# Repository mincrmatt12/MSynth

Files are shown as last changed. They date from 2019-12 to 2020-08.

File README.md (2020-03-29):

# MSynth

A simple-ish digital desktop synthesizer unit, on woefully underpowered hardware.

(well it's an STM32F429, it's really just RAM-limited, but hey it only costs ~57 cad for parts + pcbs + assembly)

## Architecture

The project is split up into multiple subprojects, each contained in a folder. They all have READMEs related to their internal structure.
User-facing documentation (i.e. a guide) is stored in the `docs/` folder.

The various subprojects are:

- `bmap`: various resource generation tools
- `board`: PCB CAD files + schematic 
- `bootloader`: The MSynth Bootloader, responsible for installation/updating/management/booting of applications and filesystem management/cleanup.
- `factory`: Test application for verifying board accuracy, component quality and basic unit tests.
- `framework`: Common code and build setup for all applications (clock setup, peripheral access code, filesystem code, etc.)
- `fstool`: Tools for generating and interacting with filesystem images
- `app`: Various primary apps are placed here. The most important one is `main_app`, which is the actual synthesizer core.

## Licensing

The MSynth project _source code_ is licensed under the ISC license (see LICENSE.txt). 
Note that any output of MSynth units is _NOT_ covered by this license; you are free to do literally anything with the audio that comes out of this project, and no warranty is provided
for these outputs (again, see LICENSE.txt).

Various font resources used (Lato and DejaVu Sans) are optionally used during the compilation process, but not included here; if you wish to avoid licensing restrictions
you may substitute other or custom fonts with more favorable licensing. 

Any graphical resources (_only in their source form in this repository_), including logos are licensed under the CC-BY-SA-4.0 license. (see LICENSE-graphics.txt)

Copyright (c) 2020, Matthew Mirvish

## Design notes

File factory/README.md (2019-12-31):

# factory

This is the "factory" testing / calibration application, which is normally installed in the TEST slot.

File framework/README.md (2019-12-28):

# MSynth App Framework

This is our replacement for platformio, since it wasn't up to this particular task.

## Create new bucket

(internal name for a set of apps)

- Copy the template cmakelists to a new folder.
- Customize it.
- Run cmake, passing `-DCMAKE_TOOLCHAIN_FILE=<path to toolchain.cmake>`
- Run cmake again, not passing the toolchain (it doesn't work the first time for whatever reason)

## Structure

```
|
-- ld: link script
-- startup: startup (+ header generation) asm
-- lib: common library for msynth
```

## App structure

Currently just contains a `src` folder per app, with all the sources.
Eventually, this will contain places to put filesystem resources/etc.

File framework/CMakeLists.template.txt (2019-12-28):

cmake_minimum_required(VERSION 3.3)
project(bucket_name_here C CXX ASM)

include(${CMAKE_CURRENT_LIST_DIR}/../framework/build.cmake)  # point at the right dir

# setup an APP
add_app(
	# folder /target name
	factory_app
	# name
	"FactoryTest"
	# appID
	"FTsc"
	# appSIZE
	16
	# flags
	TEST
	LOWSCREEN
	FS
	# valid options are: PRIMARY TEST EEPROM FS LOWSCREEN APPCMD
)

# setup an upload target
create_uploader(
	# name of taregt (to use with make)
	upload_factory
	# name of app
	factory_app
	# sector
	1
)

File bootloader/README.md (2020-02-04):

# bootloader

The MSynth bootloader is designed to allow booting of:

- one PRIMARY application (the synthesizer itself)
- one TEST application (the "factory test" )
- any number of SECONDARY applications

These applications are contained in SECTORS, which reside in contiguous flash sectors. Each sector contains a single application. The bootloader enumerates all sectors to find valid
applications.  When booting normally, the first (and only legal) PRIMARY application found is launched. If F1 and F2 are held while booting, the first (and only legal) TEST application is launched. If the
PRIMARY application cannot be found, but the TEST application can be, the TEST application is launched, otherwise the boot-menu appears. If all three mode buttons are held while booting, the boot-menu appears.

## Application Header

Each application has the following header, placed at the sector start:

| Offset | Format | Description |
| ---- | ---| --- |
| 0x00 | `"MAPP"` | 4-byte magic |
| 0x04 | char[32] | Null terminated name |
| 0x24 | u32 | Vector table offset |
| 0x28 | u32 | Entry point |
| 0x2C | char[4] | APPID |
| 0x30 | u16 | Flags |
| 0x34 | u32 | Debug data pointer (0 if not present) |
| 0x38 | u32 | Initial stack pointer |
| 0x3C | u32 | Length of application data |

The flags are:

```
                            LSB
  
X 000 10 1 01100      1 10 10                
| ||| || | |////      | |/ ||
| ||| || | |          | |  |-is PRIMARY
| ||| || | |          | |  --is TEST
| ||| || | -FSuse slot| --EEPROM slot used
| ||| || -uses FS     --uses EEPROM       
| ||| |--uses LOWscreen RAM layout
| ||| --is installed                         
| ||-- supports APPCMDs                     
| |-- uses the SD card
| -- uses the USB port
-- unused
```

The slot entries are added by the bootloader if isinstalled is not set, or during installation, if their enable bits are set. If the `LOWscreen` flag is set, the bootloader will assume the screen is setup as a
single-layer 8bpp located at the beginning of SRAM1 and SRAM2. This allows it to write messages over top of the application screen, which is useful in some cases. It assumes color 0 is black and color 1 is white.

## Memory Map

The first sector (and possibly second, depending on bootloader size) is reserved by the bootloader. No headers are present, there is effectively just a small application loaded into flash (i.e. an ISR table at flash
address 0)

The data in SRAM and CCMRAM are undefined, however in general it is split into 3 logical zones:
- SRAM1 & SRAM2 are VRAM (upper 512 bytes unused)
- SRAM3 is RAM
- CCMRAM is CCMRAM

The data in the upper 128 bytes of BKPRAM is the bootloader serialization area. When the bootloader starts, it reads from here and when it ends it writes to here.

The bootloader reserves the first 8 bytes of EEPROM.

## Bootloader Serialization Data

| Offset | Format | Description |
| --- | --- | --- |
| 0x00 | `"MBLD"` | 4-byte magic |
| 0x04 | u8 | Init flags |
| 0x05 | u8 | Boot command |
| 0x08 | u32[8] | Boot command parameters |
| 0x28 | u8 | Boot mode |
| 0x2C | u32 | PTR to APPINFO |
| 0x30 | u8 | App Special Command |
| 0x34 | u32[8] | App command parameters |
| 0x54 | u32 | App command return value |

The init flags are set based on which parts of the data are valid. These flags are:

```
		LSB
XXXX 0000
|/// ||||
|    |||-- Boot command set
|    ||-- Boot mode/APPINFO set
|    |-- App special command set
|    -- App return pointer set
-- unused
```

For example, when an application boots, bit 1 should be set, and if the bootloader is calling a special routine in the ap, bit 2 will also be set.
If an application wants to trigger a command, it should write data to the correct offsets and set bit 0, then reset.

### Boot Mode

The boot mode indicates what events caused the app to start executing, an enumeration of:

| Value | Name |
| ----- | ---- |
| 0x00  | UNKNOWN_BOOT |
| 0x10  | NORMAL_BOOT_PRIMARY |
| 0x11  | NORMAL_BOOT_TESTBUTTON |
| 0x12  | NORMAL_BOOT_KEYCODE |
| 0x20  | OVERRIDE_BOOT_PRIMARY_FAIL |
| 0x21  | OVERRIDE_BOOT_MENU |
| 0x30  | UPDATE_OK_PRIMARY |
| 0x31  | UPDATE_FAILED_PRIMARY |
| 0x32  | UPDATE_OK_BOOTLOADER |
| 0x33  | UPDATE_FAILED_BOOTLOADER |
| 0x40  | SUB_LAUNCH_BOOT |
| 0x41  | SUB_LAUNCH_DONE | 

- Normal boot refers to the system booting using key combinations or normally.
- Override boot occurs when the first choice of the system was bypassed.
- Update boot occurs after an app self-updated
- Sub launch is when an app boots another app / returns from said app.

### Special Commands

The bootloader can call into your application as an API if the flag is set in the APPINFO.
The various commands are:

| Value | Name | Arguments |
| ----- | ---- | --- |
| 0x00  | NORMAL_BOOT | none |
| 0x10  | UPDATE_FS_USE_FLAGS | none |
| 0x11  | RELOCATE_EEPROM_DATA | old sector, new sector; returns success |
| 0x20  | SUB_LAUNCH | params copied from boot command |

Normally, the value is 0, meaning a normal boot. When the filesystem is cleaned (during an update / removal) the UPDATE_FS_USE_FLAGS is called. This allows the application to mark all of the resources it uses.

## Boot State

When an app is launched, the following conditions hold:

- VTOR is set correctly for the app
- LR points to a valid return address
- MSP is set to a new stack

## Filesystem

The MSynthFS is designed for storing resources with applications. A resource is something that is any of the following:
- may be shared between apps
- not easy/practical to place in .rodata
- may be updated separately from the main app text (patch data, for example)

In effect, the MSynthFS is a collection of files; each bearing a unique filename and contents, as well as metadata.
The FS is designed to fit it a single (or if absolutely necessary, two) 128kB sector(s). Because it sits as a single sector, erasing is only
practical from the perspective of the bootloader / external device when a cleanup operation is required. As a result, many fields use
`0xff` as a placeholder, so that they may be changed later.

### Layout

The FS is divided into 16 logical sections, which make up the top-level folders (the root is considered a folder under this scheme with null name).
Each of these sections contains a linked list of files. Typically top-level folders correspond to installed applications (usually with name `$IDID`) 
however usually the last 4 are reserved for the primary application. The root folder is one of these.

### Format

The FS starts with a header:

| Offset | Format | Meaning |
| --- | --- | --- |
| 0x00 | `"MSFS"` | 4-byte magic |
| 0x04 | u8 | structure version (currently 1)
| 0x05 | u8 | number of sectors used |
| 0x06 | u16 | top-level folder use mask (inactive 1, active 0) |
| 0x08 | `TopLevel[16]` | set of top level folder (file chains) |

A `TopLevel` entry looks like:

| Offset | Format | Meaning |
| --- | --- | --- |
| 0x00 | `"fStL"` | 4-byte magic. Only present if in use |
| 0x04 | char[12] | name, null terminated |
| 0x10 | u32 | ptr to first file, 0xFFFF FFFF if no files contained |
| 0x14 | u16 | flags |
| 0x16 | u16 | reserved, should be kept 0xFFFF |

The flags are:
```
00000000 0000 0000
|///////   ||  |||
|   	   ||  ||-- system-global (fonts, img)
|          ||  |-- primary-app (patches)
|          ||  -- private-app ($TcEM)
-- users   || 
		   |-- is marked for deletion
		   -- is deleted
```

#### Files

A file contains some flags, some set of apps requesting it stay around, a potential new version and the next file.
Each file starts with this header:

| Offset | Format | Meaning |
| --- | --- | --- |
| 0x00 | `"fLeT"` | 4-byte magic |
| 0x04 | char[16] | null-terminated name |
| 0x14 | u32 | user flags |
| 0x18 | u16 | length |
| 0x2C | u16 | flags |
| 0x30 | u32 | ptr to next file (0xFFFF FFFF if end of list) |
| 0x34 | u32 | ptr to new revision of this file |

Immediately following this header (alignment is only required to 0x4) is the entire contents of the file.
If the new revision ptr is set, all data current residing in this entry is discarded and the new entry used as if it were placed here.
Finding new memory in the FS area is up to the app. Fragmentation is allowed.

The flags are:

```
11 00000 10
|| |//// ||
|| |     |-- is deleted (usually accompanied by a revision ptr of 0)
|| |     -- is marked for deletion (will be deleted at next available opportunity)
|| -- creator (31 for system)
|-- is font resource (used by the bootloader in lieu of extensions)
-- is img resource
```

#### User flags

Various filesystem objects take a set of user-flags. These are used to tell the bootloader that an app wants to keep a file around during cleanup. During the cleanup operation, the following
things happen:

- Call all APPCMDs for updating use flags
- Find the set of POTENTIAL GARBAGE files
   - For each toplevel and its files:
      - Is it a system-global toplevel:
         - Is it a font or image created by someone other than system? Add to the RSRC-USE list
      - Is it a primary toplevel:
         - If this is a PURGE-level clean, add all files to the APP-USE list.
      - Is it a private app:
         - Is the file marked for deletion?
            - Mark file as deleted
         - Is the owner a valid owner (exists in an APPINFO)?
            - ignore
         - Otherwise, add to the APP-USE list.
- For all the files in RSRC-USE list:
   - Is the file the only remaining font on the system: ignore it
   - Is the filename "splash": ignore it
   - Do any of its users exist: ignore it
   - Otherwise, mark as deleted.
- For all the files in the APP-USE list:
   - Is it marked as used by a valid app (only the primary for those in primary folders): ignore it.
   - Is it a primary resource: prompt the use for confirmation
   - Otherwise, mark as deleted
- Regenerate the filesystem, removing old revisions of files and deleted ones.

The bit to set in the user flags is marked in the APPINFO header. Values above 16 indicate unassigned, and values above 16 in the user flags themselves are reserved for bootloader use.

The user can also request for file deletion, in which case the same logic should be executed as above, except all cases where the file would be ignored instead cause a confirmation, and instead of doing a full regeneration,
just mark the files as deleted.

Prompt operations can call into APPCMDs for custom messages if there is only one user registered (e.g. "This sample is in a recently-used patch. Deleting it would require the SD card to be inserted to reinstall it").

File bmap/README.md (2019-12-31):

# `bmap` - resource file tools

These are similar to the tools located in SignCode, but instead output binary files and support slightly more options.

## `fnter` - "FoNT generatER"

Takes a font file and a size in pixels and outputs a binary file in the `MFnt` format.

The format begins with a header:

| Offset | Format | Description |
| ---- | ---| --- |
| 0x00 | `"MFnt"` | 4-byte magic |
| 0x04 | u8 | Font flags |
| 0x06 | u16 | ptr to bitmaps/metrics |
| 0x08 | u16 | length of kern table (0 if not present, number of entries) |
| 0x0A | u16 | ptr to kern table (undefined if not present) |

The font flags are:

```
0000 1 10 1
|/// | || |
|    | || -- is compressed
|    | |-- is italic
|    | -- is bold
|    -- has kerning data  
-- unused
```

### Metrics

The metrics data is the following structure:

| Offset | Format | Description |
| ---- | ---| --- |
| 0x00 | u8 | glyph width |
| 0x01 | u8 | glyph height |
| 0x02 | u8 | uncompressed: stride, compressed: "byte" length in bits (0 if using uncompressed encoding) |
| 0x03 | s8 | pen advance |
| 0x04 | s8 | bearingX |
| 0x05 | s8 | bearingY |

No alignment constraints are placed on the metrics data, and it is placed immediately before each bitmap.

### Uncompressed bitmap format
The bitmaps are stored left to right, top to bottom, though to simplify
the decoding logic the bits are reversed:

```
hgfedcba      kji
00000111 00000001  | number of bits = width; number of bytes = stride

srqponml      vut
00000001 00000010  | number of rows = height; size in bytes = stride * rows

abcdefghijk
lmnopqrstuv
```

### Compressed bitmap format

In compressed mode, the bitmaps are interpreted as a stream of prefix-encoded instructions.
The data should be read as a continuous stream of bits, and a buffer should be allocated
for the previously read row.

The first 2-3 bits make up a command, one of:

| Prefix | Meaning |
| :---: | --- |
| 10 | Copy full row of data |
| 11 | Zero byte |
| 01 | Copy next byte of data |
| 001 | Repeat previous row |
| 000 | Duplicate previous row at current byte |
| 00 | (only as first command) Copy entire bitmap verbatim |

The process of reading command, then (optionally) reading its data continues until
the entire glyph is read, based on the data in the metrics table.

Additionally, the "byte" size can be redefined in the metrics table, for more optimal compression; although
it must be a factor of the row length.

### Kerning table

The kerning table is an array of the following structure:

| Offset | Format | Description |
| ---- | ---| --- |
| 0x00 | u8 | First char |
| 0x01 | u8 | Second char |
| 0x02 | s16 | Pen offset |

The structure should be aligned to 2 bytes.

## `readfnt` - "READ FoNT"

This tool reads a font, and shows all of its internal data in an easy to see manner. This is mostly present for verifying the output of `testfnt`.

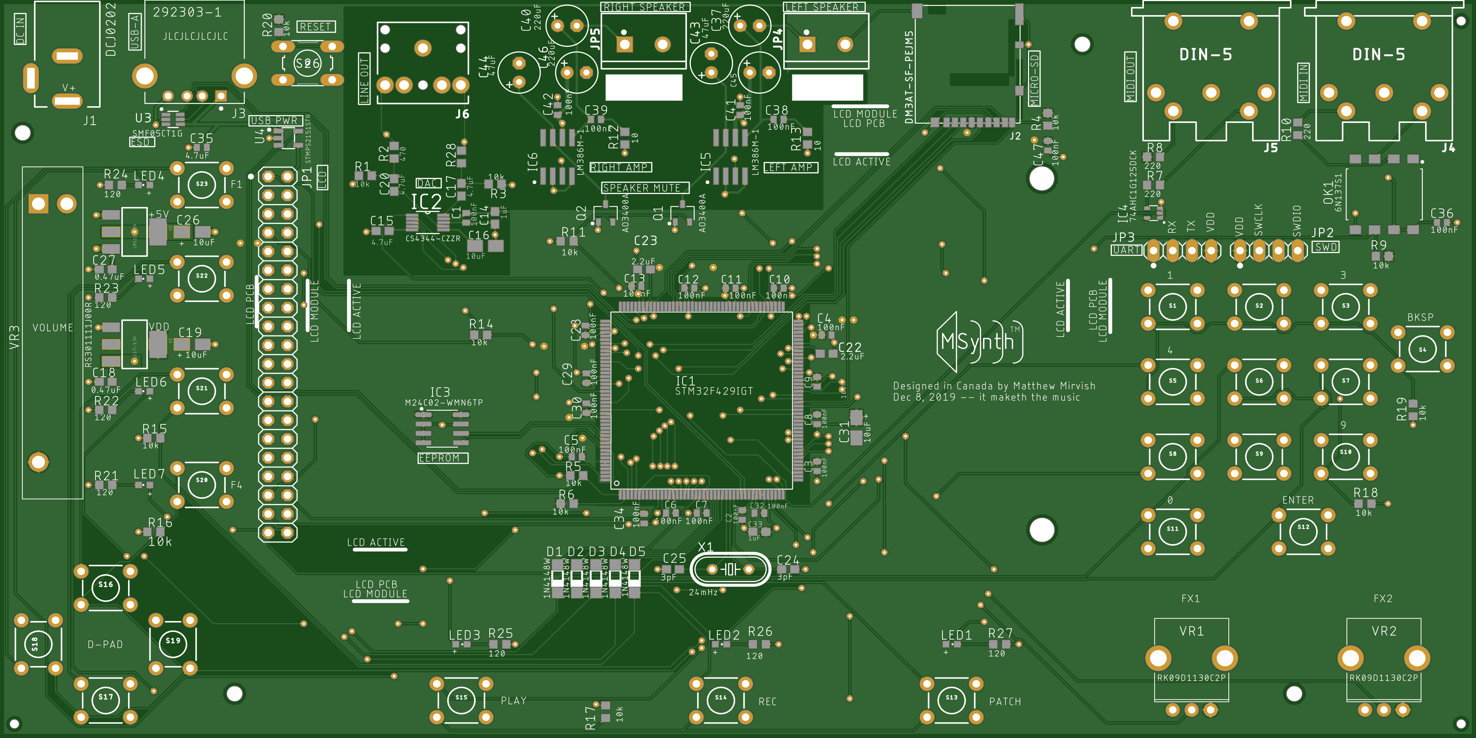
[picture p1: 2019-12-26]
board/mainboard.png

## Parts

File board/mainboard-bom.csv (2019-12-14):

Qty | Parts | Footprint | LCSC Part # | Description | Value
2 | C18, C27 | C0603 | C1623 | CAPACITOR, European symbol | 0.47uF
2 | R12, R13 | R0603 | C22859 | RESISTOR, American symbol | 10
24 | C1, C2, C3, C4, C5, C6, C7, C8, C9, C10, C11, C12, C13, C28, C29, C30, C32, C34, C36, C38, C39, C41, C42, C47 | C0402 | C1525 | CAPACITOR, European symbol | 100nF
14 | R1, R3, R4, R5, R6, R9, R11, R14, R15, R16, R17, R18, R19, R20 | R0603 | C25804 | RESISTOR, American symbol | 10k
4 | C16, C19, C26, C31 | A/3216-18R | C7171 | POLARIZED CAPACITOR, American symbol | 10uF
7 | R21, R22, R23, R24, R25, R26, R27 | R0603 | C22787 | RESISTOR, American symbol | 120
7 | LED1, LED2, LED3, LED4, LED5, LED6, LED7 | CHIPLED_0603 | C72041 | LED | 19-217/BHC-ZL1M2RY/3T
5 | D1, D2, D3, D4, D5 | SOD123 | C81598 | DIODE | 1N4148W
2 | C14, C33 | C0603 | C15849 | CAPACITOR, European symbol | 1uF
3 | C22, C23 | C0603 | C23630 | CAPACITOR, European symbol | 2.2uF
3 | R7, R8, R10 | R0603 | C22962 | RESISTOR, American symbol | 220
3 | C15, C17, C20 | C0603 | C19666 | CAPACITOR, European symbol | 4.7uF
2 | C24, C25 | C0603 | C46219 | CAPACITOR, European symbol | 3pF
1 | C35 | C0402 | C23733 | CAPACITOR, European symbol | 4.7uF
2 | R2, R28 | R0603 | C23179 | RESISTOR, American symbol | 470
1 | OK1 | SOP254P1030X390-8L | C110020 | MOTOROLA OPTO COUPLER | 6N137S1
1 | IC4 | SC70-5 | C151890 | Single Bus Buffer Gate with 3-State Output | 74AHC1G125DCK
2 | Q1, Q2 | SOT95P280X125-3L | C20917 | transistor; mosfet | AO3400A
1 | U1 | SOT223 | C6186 | Voltage Regulator LM1117 | LM1117-3.3V
1 | U2 | SOT223 | C6187 | Voltage Regulator LM1117 | LM1117-5V
2 | IC5, IC6 | SO08 | C23573 | Low Voltage Audio Power Amplifier | LM386M-1
1 | IC3 | SOIC127P600X175-8N | C7562 |  | M24C02-WMN6TP
1 | U3 | SOT65P210X110-6N | C15879 | SMF05C Series 7.2 V 100 W 5-Line Transient Voltage Suppressor Array - SC-88 | SMF05CT1G
1 | IC1 | LQFP176 | C54328 | ARM 32-bit Cortex™-M3 CPU | STM32F429IGT
1 | U4 | SOT23-5L | C135998 | usb pwr | STMPS2151STR
1 | IC2 | SOP50P490X110-10N | C8952 | dac | CS4344-CZZR

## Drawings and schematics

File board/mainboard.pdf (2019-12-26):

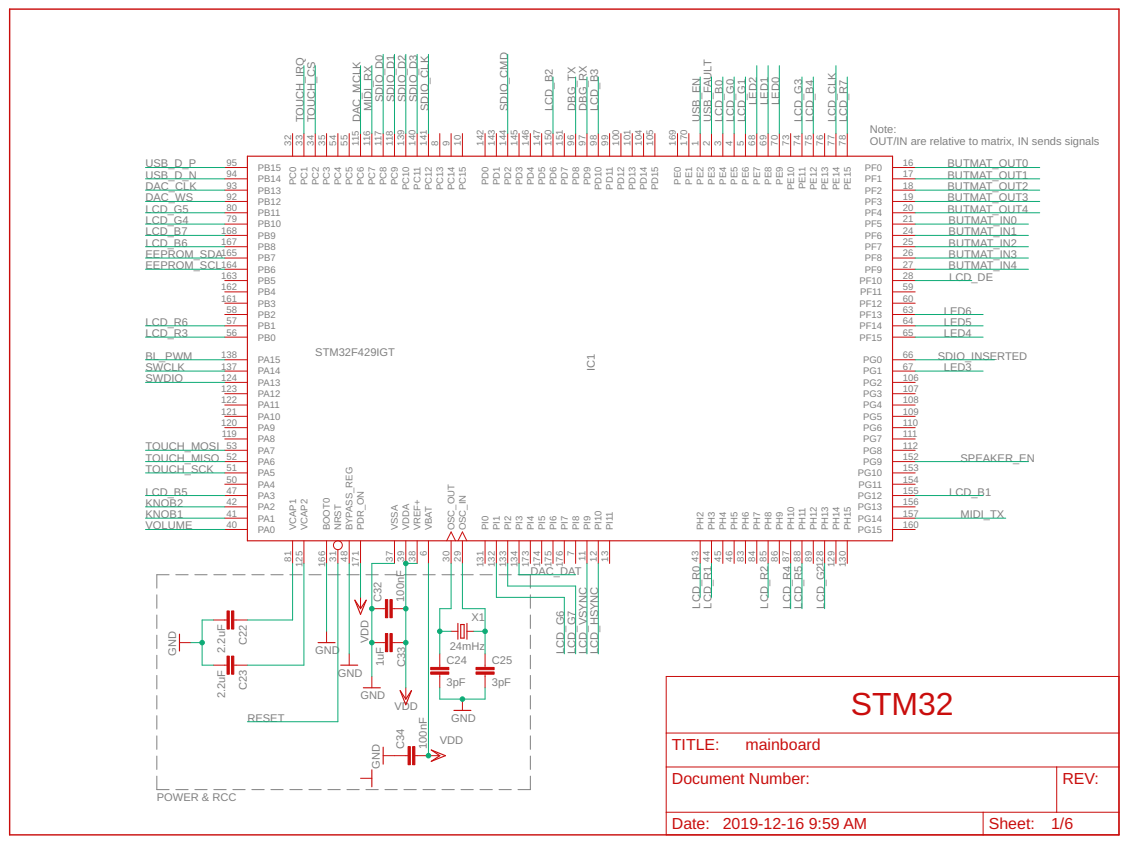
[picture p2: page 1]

Note: OUT/IN are relative to matrix, IN sends signals

Document Number: | REV:

Date: 2019-12-16 9:59 AM | Sheet: 1/6

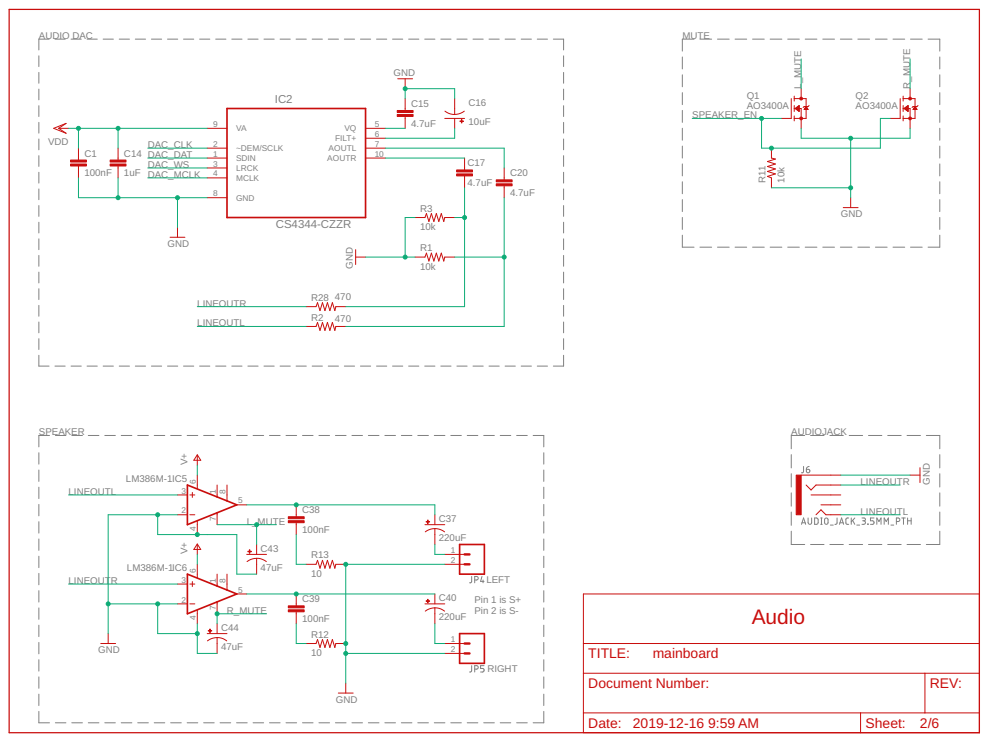
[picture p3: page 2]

LEFT
Pin 1 is S+ Pin 2 is S-

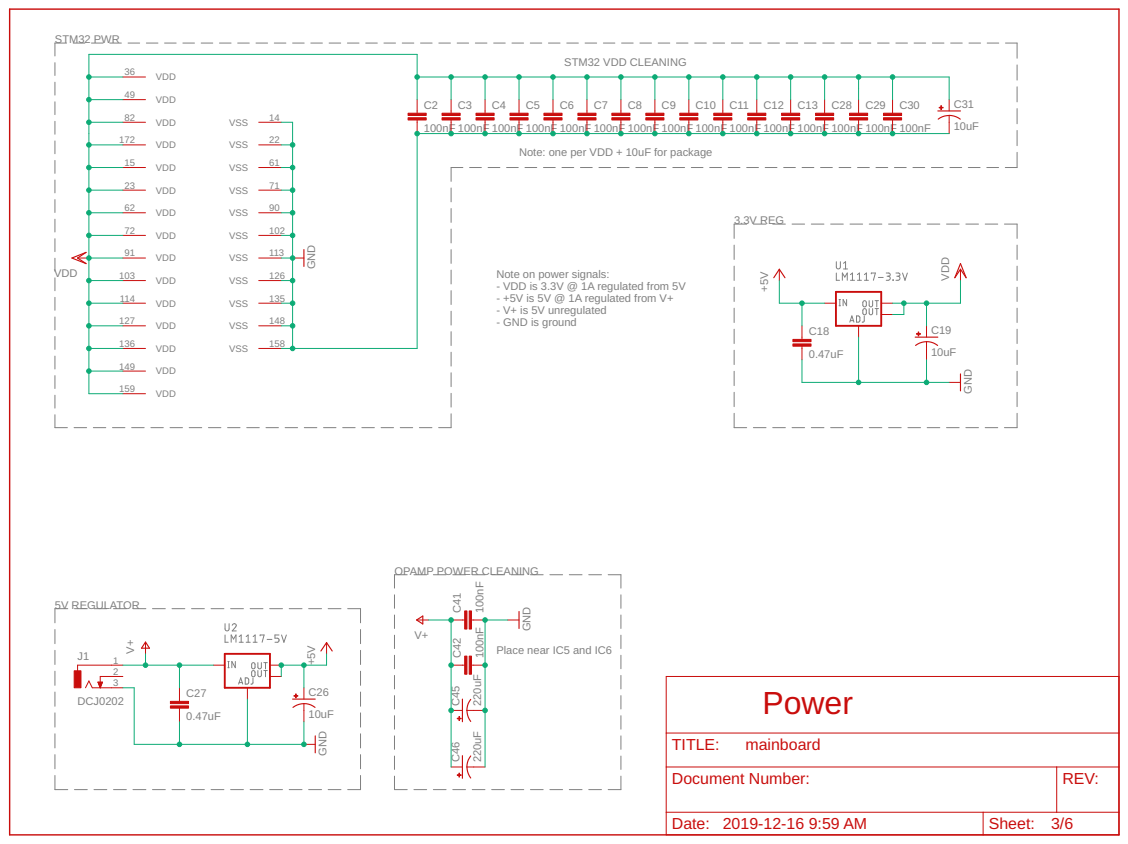
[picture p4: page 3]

Note: one per VDD + 10uF for package

Note on power signals: - VDD is 3.3V @ 1A regulated from 5V
- +5V is 5V @ 1A regulated from V+
- V+ is 5V unregulated
- GND is ground

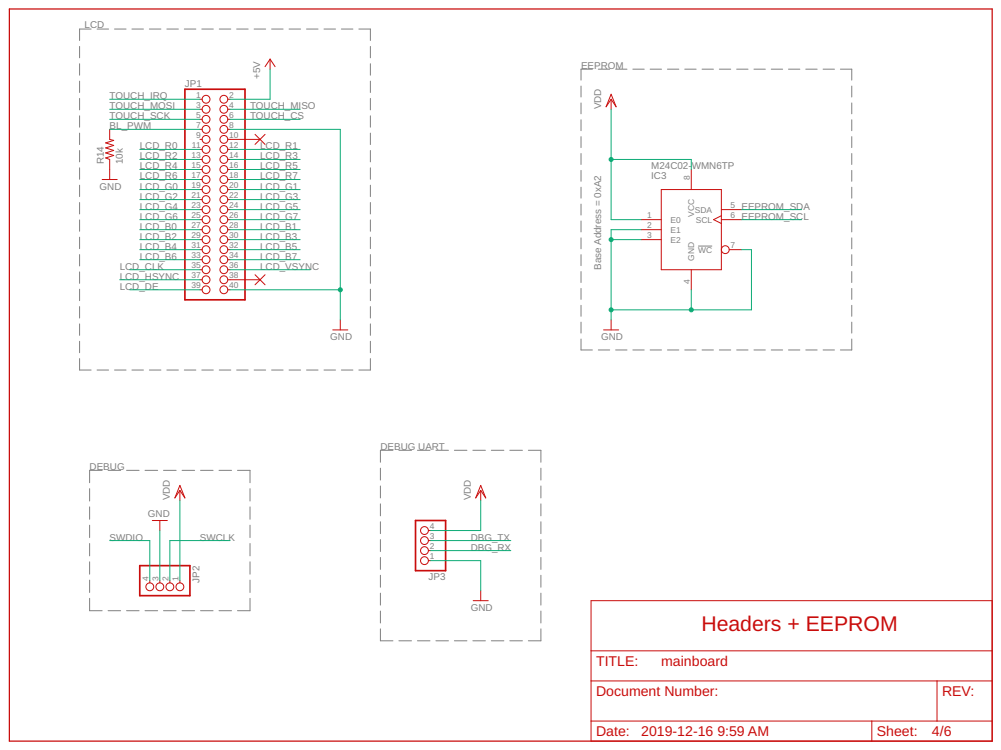
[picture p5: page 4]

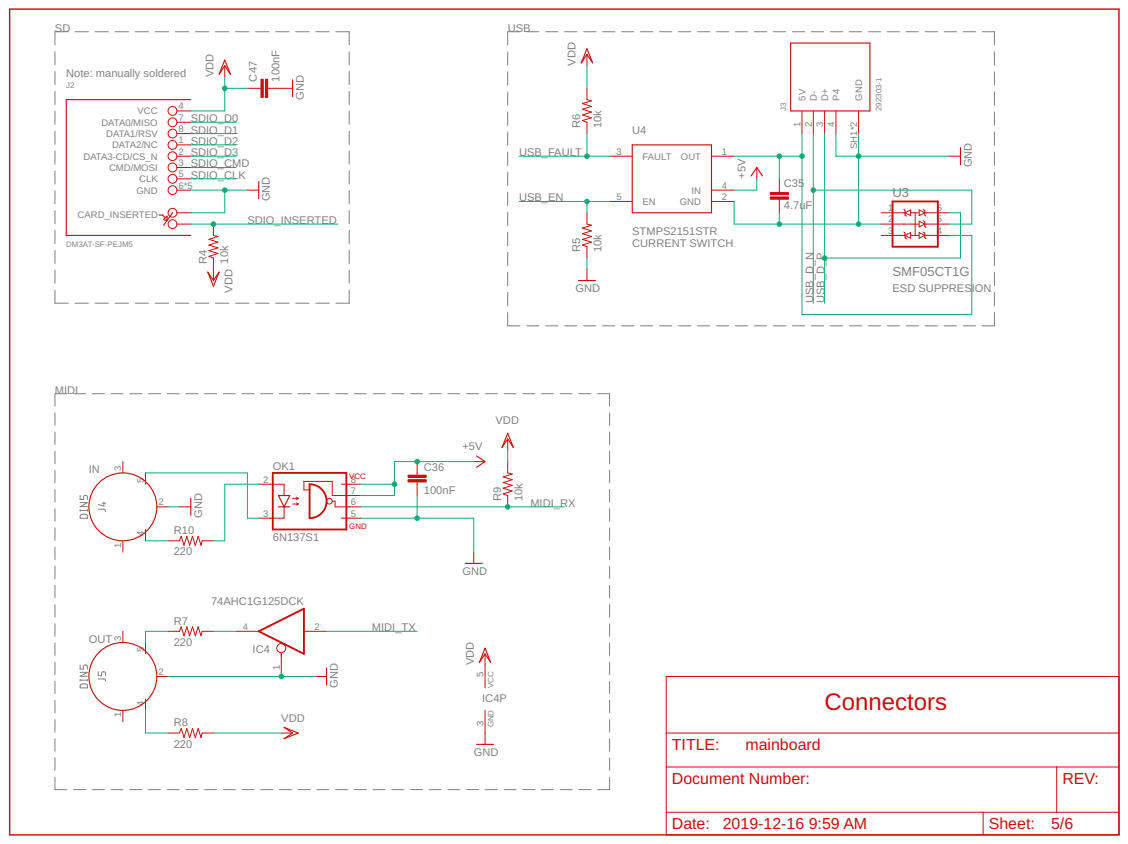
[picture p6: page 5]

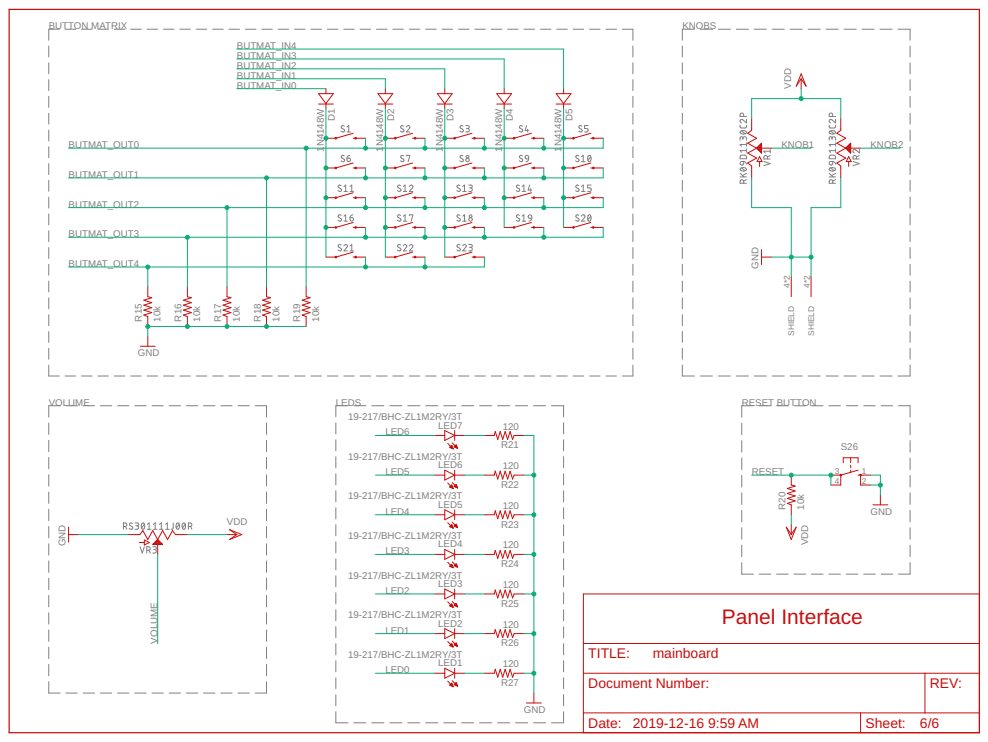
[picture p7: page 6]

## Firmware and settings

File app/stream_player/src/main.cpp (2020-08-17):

#include "stm32f4xx_ll_dma.h"
#include <cmath>
#include <stdio.h>
#include <msynth/periphcfg.h>
#include <msynth/lcd.h>
#include <msynth/draw.h>
#include <msynth/usb.h>
#include <msynth/sound.h>
#include <msynth/sd.h>
#include <msynth/fs.h>

#define BUFSIZE 8192

ISR(SDIO) {
	sd::sdio_interrupt();
}

const void * uiFnt;

int16_t buffers[2][BUFSIZE];
bool sd_is_transferring = false;
bool not_up_to_date_flag = false;

uint32_t pos = 0;
uint32_t size = 0;

int16_t voltagediv = 1;

void output(const char * txt) {
	static uint16_t y = 50;
	if (y > 270) {
		draw::rect(0, 36, 480, 272, 0xff);
		y = 50;
	}
	draw::text(1, y, txt, uiFnt, 0x00);
	y += 16;
	puts(txt);
}

template<typename ...Args>
inline void output(const char *fmt, Args& ...args) {
	char buf[128];
	snprintf(buf, 128, fmt, std::forward<Args>(args)...);
	output(buf);
}

void sd_read_callback(void *arg, sd::access_status status) {
	if (pos * 512 >= size) {
		output("pos = %d; size = %d", pos, size);
		output("Done!");
		sound::stop_output();
		return;
	}
	if (status != sd::access_status::Ok) {
		output("read failed");
		LL_DMA_DisableStream(DMA1, LL_DMA_STREAM_4);
		return;
	}
	if (not_up_to_date_flag && sd_is_transferring) {
		LL_DMA_DisableStream(DMA1, LL_DMA_STREAM_4);
		// Handle behind
		output("behind");

		if (/*the active buffer is b1*/ arg == buffers[1]) {
			memcpy(buffers[0], buffers[1], BUFSIZE);
		}

		sd_is_transferring = false;
		sd::read(pos, buffers[1], BUFSIZE/256, sd_read_callback, nullptr);
		pos += BUFSIZE/256;
	}
	else if (not_up_to_date_flag) {
		output("restart");
		sd_is_transferring = false;
		not_up_to_date_flag = false;

		sound::setup_double_buffer(buffers[0], buffers[1], BUFSIZE / 2);
	}
	else {
		for (int i = 0; i < BUFSIZE; ++i) {
			((int16_t *)(arg))[i] /= voltagediv;
		}
		if (!(pos % 0x800)) output("pos = %d", pos);
		sd_is_transferring = false;
	}
}

// STREAM SYSTEM
//
// Initially both buffers are setup, once a buffer is sent, we try to load the next one.
// If this completes before the next TCIF of the sound buffer, we keep going.
// Otherwise, the sound output is paused. If this occurs, the SD handler will start another transfer, which when complete will restart the process.

ISR(DMA1_Stream4) {
	if (LL_DMA_IsActiveFlag_TE4(DMA1)) {
		LL_DMA_ClearFlag_TE4(DMA1);
		output("DMA TE!");
		LL_DMA_DisableStream(DMA1, LL_DMA_STREAM_4);
		return;
	}
	else if (!LL_DMA_IsActiveFlag_TC4(DMA1)) return;
	LL_DMA_ClearFlag_TC4(DMA1);

	// TC is set, we check if sd_is_transferring
	if (!sd_is_transferring && sd::card.active_state != sd::Card::ActiveStateReading) {
		// Good, we can continue and start the SD to fill up this current buffer
		int16_t * buf = LL_DMA_GetCurrentTargetMem(DMA1, LL_DMA_STREAM_4) == LL_DMA_CURRENTTARGETMEM1 ? buffers[0] : buffers[1];
		sd_is_transferring = true;
		if (sd::read(pos, buf, BUFSIZE/256, sd_read_callback, buf) != sd::access_status::InProgress) {
			output("Read failed");
			LL_DMA_DisableStream(DMA1, LL_DMA_STREAM_4);
		}
		pos += BUFSIZE/256;
	}
	else {
		not_up_to_date_flag = true;
	}
}

int main() {
	periph::setup_dbguart();
	periph::setup_blpwm();
	periph::setup_ui();
	puts("\nStarting MSynth v0");
	periph::bl::set(160);
	lcd::init();
	draw::fill(0xff);
	puts("Starting filesystem");
	if (!fs::is_present()) {
		puts("filesystem check failed");
		return 1;
	}
	const void * bigFnt = fs::open("fonts/lato_32.fnt");
	uiFnt = fs::open("fonts/djv_16.fnt");
	draw::text(1, 33, "MSynth SD player", bigFnt, 0);

	output("Starting SD");
	sd::init();
	output("Waiting for SD card");
	output("It should have a 4byte size with audio data");
retry:
	while (!sd::inserted()) {
		;
	}
	output("Starting SD card");
	auto status = sd::init_card();
	if (status != sd::init_status::Ok) {
		switch (status) {
			case sd::init_status::CardUnusable:
				output("err CardUnusable");
				break;
			case sd::init_status::CardNotInserted:
				output("err CardNotInserted");
				break;
			case sd::init_status::MultipleCardsDetected:
				output("err MultipleCardsDetected");
				break;
			case sd::init_status::CardNotResponding:
				output("err CardNotResponding");
				break;
			case sd::init_status::CardIsSuperGluedShut:
				output("err CardIsSuperGluedShut");
				break;
			case sd::init_status::CardIsElmersGluedShut:
				output("err CardIsElmersGluedShut");
				break;
			case sd::init_status::NotInitialized:
				output("err NotInitialized");
				break;
			case sd::init_status::InternalPeripheralError:
				output("err InternalPeripheralError");
				break;
			case sd::init_status::NotSupported:
				output("err NotSupported");
			default:
				break;
		}
		while (1) {;}
		return 1;
	}
	output("Ok");

	output("Checking size of data");
	uint8_t data[512];
	if (sd::read(0, data, 1) != sd::access_status::Ok) {
		output("failed");
	};

	size = *(uint32_t *)(data);
	output("Data size = %d", size);
	util::delay(100);
	output("Enabling NVIC");
	NVIC_EnableIRQ(DMA1_Stream4_IRQn);
	NVIC_SetPriority(DMA1_Stream4_IRQn, NVIC_EncodePriority(NVIC_GetPriorityGrouping(), 5, 0));

	memset(buffers[0], 0, sizeof(buffers[0]));
	memset(buffers[1], 0, sizeof(buffers[1]));

restart:
	output("Starting");
	if (sd::read(pos, buffers[0], BUFSIZE/256) != sd::access_status::Ok) {
		output("R1 fail");
		util::delay(50);
		goto retry;
	}
	if (sd::read(pos+BUFSIZE/256, buffers[1], BUFSIZE/256) != sd::access_status::Ok) {
		output("R2 fail");
		util::delay(50);
		goto retry;
	}
	pos += (BUFSIZE/256);
	output("Read 16k samples");
	output("Starting audio player!");
	sound::init();
	util::delay(10);

	sound::setup_double_buffer(buffers[0], buffers[1], BUFSIZE / 2);
	// Main MSynth start
	while (1) {
		util::delay(1);
		auto current = (float)periph::ui::get(periph::ui::knob::VOLUME);
		auto target_max = (std::pow((4096 - current) / 4096.0f, 2.5f) * 32768.f);
		current = std::max(1.f, std::min(32767.0f, 32768.f / target_max));

		auto old = voltagediv;
		voltagediv = std::round(current);

		if (!LL_DMA_IsEnabledStream(DMA1, LL_DMA_STREAM_4)) goto restart;
	}

	return 0;
}

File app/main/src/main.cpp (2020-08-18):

#include "in.h"
#include "irq.h"
#include "audio.h"

#include <stdio.h>

#include <msynth/fs.h>
#include <msynth/periphcfg.h>
#include <msynth/draw.h>
#include <msynth/lcd.h>
#include "synth/module.h"

#include "synth/modules/waves.h"
#include "synth/patch.h"
#include "synth/live.h"
#include "ui/mgr.h"
#include "malloc.h"

int main() {
	// Setup debug UART
	periph::setup_dbguart();

	puts("");
	puts("Starting MSynth Main");
	puts("--------------------");
	puts("Version: 0.0");

	// Make sure the filesystem was flashed correctly
	if (!fs::is_present()) {
		puts("filesystem is missing; startup cannot continue.");
		return MSYNTH_APPCODE_MISSINGRSRC;
	}
	else {
		if (!fs::exists("fonts/djv_16.fnt")) {
			puts("no uifnt present.");
			return MSYNTH_APPCODE_MISSINGRSRC;
		}
	}

	// Load the UI font (for rendering loading status)
	const void * ui_font = fs::open("fonts/djv_16.fnt");
	auto status = [&ui_font](const char * v){
		draw::rect(80, 195, 340, 220, 0);
		auto x = 240 - draw::text_size(v, ui_font) / 2;
		draw::text(x, 212, v, ui_font, 0xea);
	};

	// Start the display
	lcd::init();
	periph::setup_blpwm();
	periph::bl::set(100);

	// Show a splash screen while we init
	{
		if (!fs::exists("ui/logo.img")) {
			puts("missing logo");
			draw::text(180, 130, "(no logo present)", ui_font, 0xff);
		}
		else draw::blit(190, 111, 100, 50, reinterpret_cast<const uint8_t *>(fs::open("ui/logo.img")));
	}

	status("Starting...");

	// Initialize some stuff.
	ms::irq::init();
	status("Initializing input...");
	ms::in::init();
	status("Initializing sound...");
	ms::audio::init();
	status("Setting up UI...");
	util::delay(100); // TODO: remove me when there's more loading tasks... lol
	ms::ui::ui_16_font = ui_font; // set ui font
	status("Loading settings...");

	// TODO: read previous UI state / serialize UI state and start the correct UI
	// TODO: check if we need to start the SD card
	
	status("Loading patch...");

	// temp: setup a synth
	ms::synth::Patch patch;
	{
		ms::synth::mod::SqwWave x;
		ms::synth::mod::SqwWave::Cfg x_config;

		x.amplitude = 0.03f;
		x.dc_offset = 0.f;
		x.duty = 0.3f;

		const ms::synth::Patch::ModuleHolder *sqw1 = patch.add_module(std::make_unique<ms::synth::Patch::ModuleHolder>(ms::synth::mod::SqwModule, &x_config, &x));

		ms::synth::mod::TriangleWave vib;
		ms::synth::mod::TriangleWave::Cfg vib_config;

		vib.amplitude = 2;
		vib.frequency = 8;

		const ms::synth::Patch::ModuleHolder *vibrato = patch.add_module(std::make_unique<ms::synth::Patch::ModuleHolder>(ms::synth::mod::TriModule, &vib_config, &vib));
	
		// Hook up to main output
		patch.link_modules(sqw1, ms::synth::predef::ModuleRefGlobalOut, 0, 0);
		// Hook up to dc_offset
		patch.link_modules(ms::synth::predef::ModuleRefGlobalIn, vibrato, ms::synth::predef::GlobalInPitchIdx, 2);
		// Hook up output of vibrato to frequency
		patch.link_modules(vibrato, sqw1, 0, 0);
	}

	// Create an liveplayback
	ms::synth::playback::LivePlayback<10> playback(patch);

	// Add it to the event pool
	ms::evt::add(&playback);
	// Set it as the source
	ms::audio::add_source(&playback);
	// Start audio subsystem
	ms::audio::set_volume(32767);
	ms::audio::start();
	status("Starting main loop...");

	struct mallinfo g = mallinfo();
	printf("arena %d; uord %d; ford %d\n", g.arena, g.uordblks, g.fordblks);
	
	while (1) {
		util::delay(1);
		ms::in::poll();
		ms::ui::mgr::draw();
	}


	return 0;
}

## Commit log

2019-12-07 board layout
    [mainboard.brd, mainboard.sch]
2019-12-07 board route 1/
    [mainboard.brd, mainboard.sch]
2019-12-09 final brd
    [mainboard.brd, mainboard.sch]
2019-12-09 fix silk size
    [mainboard.brd]
2019-12-14 final board / ordered
    [mainboard-bom.csv, mainboard.brd, mainboard.sch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]
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2019-12-28 framework: Add init routines + LCD/BL handler code
    Also it builds single apps
2019-12-28 bootloader: remove buckets and replace with monolithic applications
    [boot.c, main.c]
2019-12-28 factory, framework: add better build
2019-12-29 framework: Add ui (button + knob + led)
2019-12-31 framework: Adjust app ld size reporting
2019-12-31 framework: Remove wrong fpu entry
2019-12-31 framework: add lazy filtering on ADCs and adjust bl
2019-12-31 framework: lib: Rearrange includes on lib for better encapsulation
2019-12-31 framework: lib: Add filesystem and font renderer
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2020-01-01 framework: Enable I/D-cache and ART
2020-01-01 framework: lib: Add soft-rect drawing routines
2020-01-01 framework: lib: clarify lack of DMA2d support
2020-01-02 framework: lib: Update to use single byte kerning offset
2020-01-05 framework: lib: Preliminary audio support
2020-01-05 framework: lib: increase lcd VFP for more v-blank time
2020-01-05 framework: default to system gcc for better lto debugging
2020-01-05 framework: lib: reorder sound operations for faster response
2020-01-05 framework: lib: add basic debounce to ui::poll
2020-01-06 framework: lib: fix default CLUT setup
2020-01-06 framework: lib: stub SD card headers
2020-01-06 framework: lib: add note about broken SPEAKER_EN line
2020-01-25 framework: lib: lcd style fix
2020-01-25 framework: lib: more sd h
2020-01-27 framework: lib: Add delay function with systick
2020-01-27 framework: lib: sd driver basic card determination
2020-01-27 framework: lib: initialize SD card -CSD reading
2020-01-27 framework: add option to disable LTO
2020-01-28 framework: lib: Proper sd struct alignment + reg_bit
2020-01-28 framework: lib: add extra sd error codes
2020-01-28 framework: sd: make reg_bit use bools for LocalSize=1
2020-01-28 framework: lib: fix bit offset
2020-01-28 framework: lib: untested sd initializer
2020-01-29 framework: lib: fix sd build issues
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2020-01-30 framework: lib: add nop to delay
2020-01-30 framework: lib: make sd command timeout 50ms
2020-01-30 framework: lib: less jank sd size detection
2020-01-30 framework: lib: add sd pullup resistors
2020-01-30 framework: lib: correctly start SDIO clocks
2020-01-30 framework: sd: adjust check pattern and init delay
2020-01-30 framework: lib: change sd ACMD41 loop to deal with CRC and busy line
2020-01-30 framework: sd: copy response early + better clearing flags
2020-01-30 framework: sd: crappy hack because i can't solder for shit
2020-01-30 framework: change disable_lto logic
    makes it work correctly when not defined
2020-01-30 framework: lib: fix ~~"i am a noam" issue~~ incorrect bitshifts
    bitshift in reg_bit::operator was wrong way around
2020-01-30 framework: lib: extra clear template params
2020-01-30 framework: lib: ignore RESPCMD for long responses
2020-01-30 framework: sd: add 5 ms delay after CID for reasons
2020-01-30 framework: sd: cast size to u64
2020-01-30 framework: sd: fix card size v < 2
2020-01-30 framework: sd: use 4 bit databus
2020-01-31 framework: fix disable_lto again
2020-01-31 framework: sd: add extra error code for access
2020-01-31 framework: sd: add scr reg
2020-01-31 framework: sd: create clear_sd_flags
2020-01-31 framework: sd: disable widebus for now
2020-01-31 framework: sd: check size errors
2020-01-31 framework: sd: add read
2020-01-31 framework: sd: enable 4-bit mode
    but not high-speed clock; that's still borked
2020-02-04 framework: sd: adaptive clock-rate for polling reads
    it seems to work better with DMA, but for polling just slow the thing
    down
2020-02-04 framework: sd: minor header change
2020-02-04 framework: system: use maximum nvic prio bits
2020-02-22 framework: fix interrupt weak overriding
2020-02-22 framework: util: add AVR-style ISR macro
2020-02-22 framework: sd: add DMA card read
2020-02-23 framework: sd: add multi-sector reads
2020-02-23 framework: sd: fix inserted check
2020-02-23 framework: sd: remove stdio.h
2020-02-24 framework: usb: add initial API template
2020-02-24 framework: build with -ggdb3 for better debugging
2020-02-24 framework: usb: host initialization
2020-02-24 framework: usb: add dynamicstateholder and fix references
2020-02-24 framework: usb: fix assign memory leak
2020-02-25 framework: usb: more progress
2020-02-25 framework: usb: finish preliminary usb host init
    device enumeration is to follow
2020-02-26 framework: usb: switch to _HS
    you'd think i was able to read my own documentation
    also no more nice reset b.c. stm are idiots
2020-02-26 factory: simple usb test
    currenty detects devices and gets through init
2020-02-26 framework: usb: debounce on power on
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2020-03-01 framework: usb: basic xfers complete
    why in gods name
    does a register
    kill itself?
    why does anything work
    what is the meaning of life
2020-03-20 framework: usb: Various fixes to get to phase 2 of enumeration
2020-03-21 framework: usb: Rewrite channel handling to get enumeration working
    It can now init a midi keyboard!
    Notes:
    - Channels will now auto-retry xfers.
    - Retry behavior can either be:
    - Instant, which does the retry as soon as possible
    - CPUDelayed, which will run util::delay(2) (only use in non-critical areas)
    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
2020-03-21 framework: usb: add callback specialization for function objects
2020-03-21 framework: usb: fix retry for OUT transmissions
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2020-03-22 framework: usb: fix EPTYP detection for DPID generation
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2020-03-22 framework: sound: allow continuous_sample to be ran while dmaing
2020-03-22 framework: usb: add retry step for one of the enum transfers
    some buggy usb implementations seem to have a habit of failing there
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2020-03-22 framework: usb: Add common state + control req helpers
2020-03-22 framework: usb: fix pipe_t
2020-03-23 board: fix usb power switch pins
    [mainboard.brd, mainboard.sch]
2020-03-23 framework: usb: move reset delay retry
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2020-03-23 framework: usbdev: fix configuration set
2020-03-23 framework: sound: fix continuous_sample
2020-03-28 bootloader: reset peripherals before app launch
    [boot.c]
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2020-03-28 framework: sd: timeout in FIFO read fail
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2020-04-29 app: ui: fix button transient event handling
2020-04-29 app: ui: make button activate when you let go
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2020-04-30 app: ui: fix button release
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2020-05-02 app: ui: add focusable button type
    (because reasons)
2020-05-02 app: ui: shade button while pressed through keyboard
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2020-08-11 framework: link ISR table after text for better packing
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2020-08-15 app: synth: fix bugs in jit
    [jit.h]
2020-08-15 app: synth: fix unsigned constant in JIT
    [jit.h]
2020-08-15 app: synth: fix jit literalpool offset
    [jit.h]
2020-08-17 app: playback: don't cut notes if not released yet
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2020-08-18 framework: move heap into ram and move vram into high ram
2020-08-18 app: irq: fix name of usb interrupt + lower priority of audio
2020-08-18 app: synth: don't cut off polyphony with no-release time
2020-08-18 app: synth: fix param order in jit
    [jit.h]
2020-08-18 framework: add c++ library stubs for operator new/delete and exceptions
2020-08-18 app: more debug vibrato stuff
    [main.cpp]
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2020-09-07 board: revb schematic
    [mainboard-revb.sch]
2020-09-14 app: audio: do evil vtable magic to avoid checking audiogen each sample
